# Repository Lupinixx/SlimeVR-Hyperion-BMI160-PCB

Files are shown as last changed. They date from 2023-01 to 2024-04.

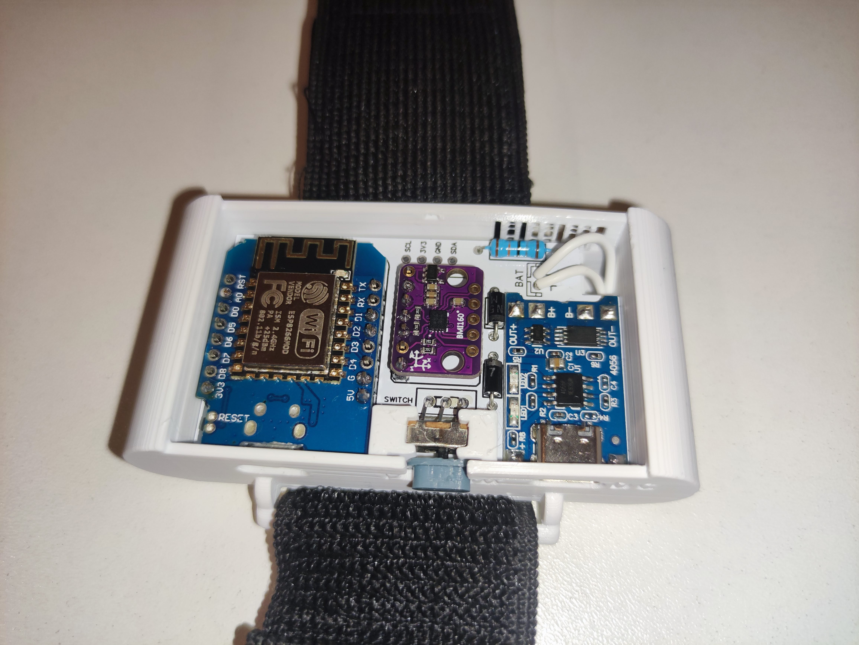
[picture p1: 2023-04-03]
Photos/IMG_20230331_202753.jpg

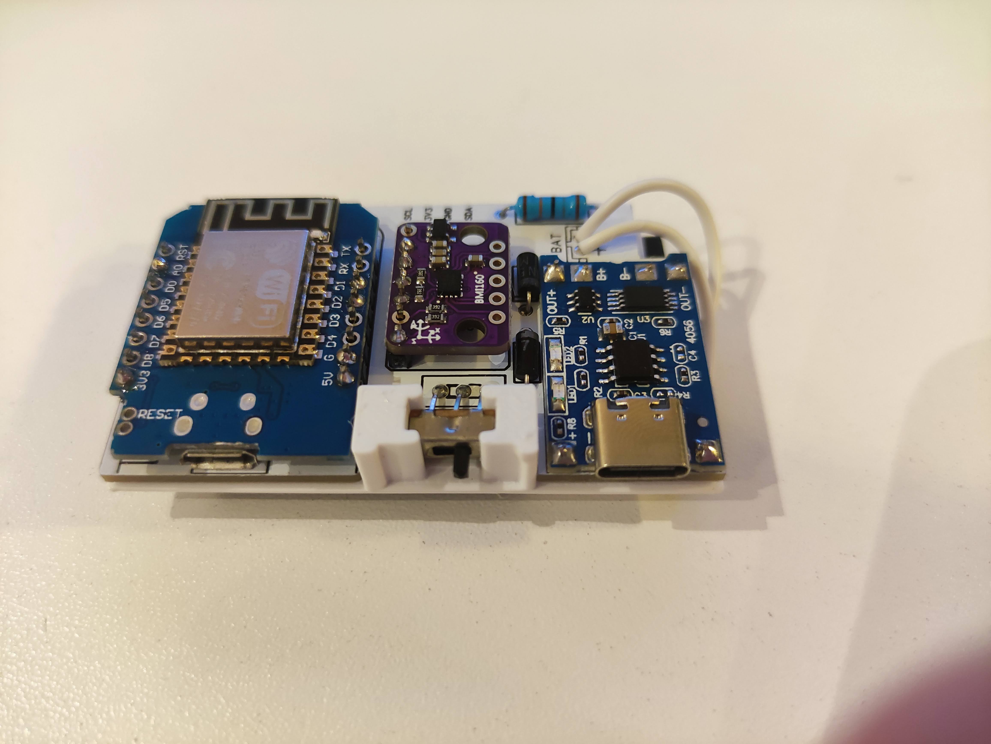
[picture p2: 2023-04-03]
Photos/IMG_20230331_202522.jpg

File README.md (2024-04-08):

# Direct order from PCBWay (This does support me a bit!)
https://www.pcbway.com/project/shareproject/SlimeVR_Hyperion_BMI160_PCB_ddd64fe3.html

# Modified Hyperion case for SlimeVR with PCB for BMI160 IMU

This is a modified version Hyperion case made to fit a custom made PCB that holds standard SlimeVR components and a BMI160 IMU. <br>
Includes a modified lid with holes to allow you to see the LEDs on the PCB inside. <br>
The original design of the case is made by Smeltie and can be found here: https://github.com/Smeltie/Hyperion <br>
The 804040 battery variant of the case is made by Discord user 'Tamate Momochi#9595' <br>
The STEP Conversion was provided by [The4thGoose](https://github.com/The4thGoose) <br>

## Components
This Case/PCB is made for the standard DIY SlimeVR components that are recommended in the docs. you can check the docs for links to the specific componets here: https://docs.slimevr.dev/diy/components-guide.html <br>
Only difference is to the docs the switch used, which is smaller and looks nicer (standard for the hyperion case) <br>
The IMU used is the BMI160. <br>

- TP4056
- Wemos D1 Mini
- BMI160
- 40MM Straps
- SS12D00G3 (switch)
- Battery
    - 503759 (Nokia BL-5C also fits this version and is also a cheap alternative. Bit harder to solder as it does not come with battery leads.)
    - 804040
- 1N5817 Diode (2x)
- 180K Ohm resistor

## PCB
Included in this repo are the gerber files that can be uploaded at [JLCPCB](https://jlcpcb.com/) <br>
Or you can directly order from PCBWay from here https://www.pcbway.com/project/shareproject/SlimeVR_Hyperion_BMI160_PCB_ddd64fe3.html
The source of this PCB can be found at:  https://oshwlab.com/lupinix/slimevr-hyperion-bmi160

## Building
The PCB is made for the above mentions components to be soldered on with the pin headers that are (almost always) included with those components.
The TP4056 however has to be directly soldered to the PCB so there is no gap between PCB and the TP4056. What I like to do is lign up the holes of the TP4056 and the PCB and then throw in a short snipped off resistor lead, and then solder it from both sides. This way you can be sure there is electrical contact between the PCB and TP4056. <br>
The Resistor and diodes can just be soldered like a regular troughhole component. <br>
For the switch I reccomend to first solder everything else, put the PCB on the 3D printed tray, then push the switch in place and solder it.

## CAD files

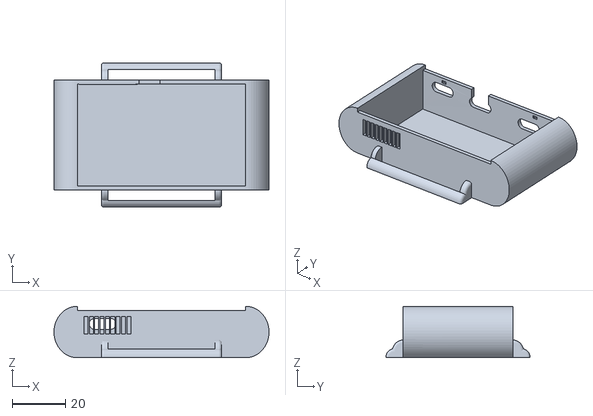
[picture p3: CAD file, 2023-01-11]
503759 case/Case_503759.stl
80.5 x 54.0 x 19.2

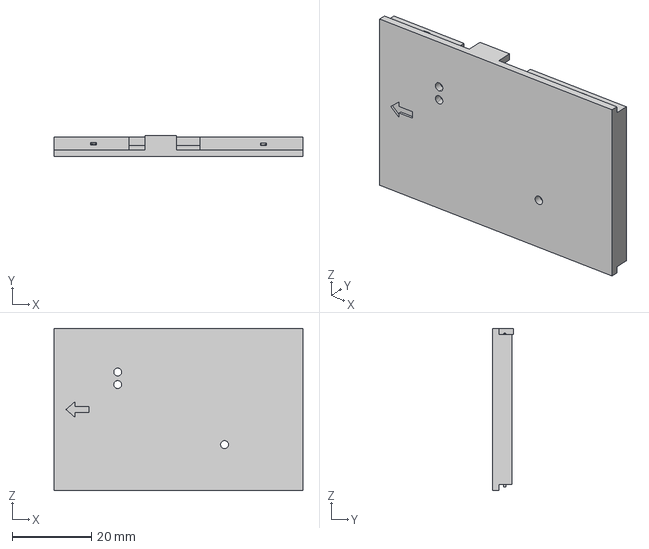
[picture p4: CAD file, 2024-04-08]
503759 case/STEP Files/Lid.step
63.0 x 5.37 x 41.0 mm

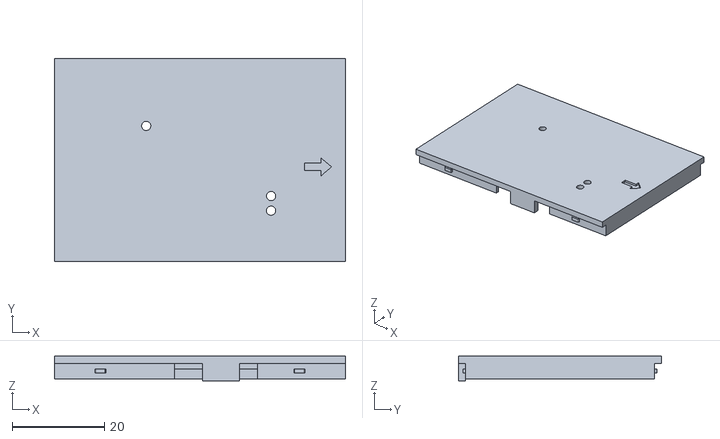
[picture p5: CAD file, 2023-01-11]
804040 case/Lid_804040.stl
63.0 x 44.0 x 5.37

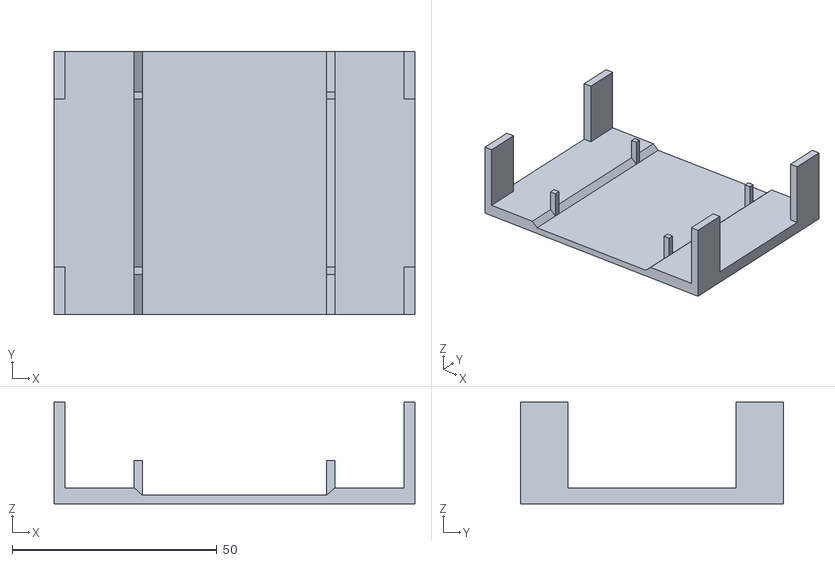
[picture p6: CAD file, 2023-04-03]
Hyperion Lupinix-calibration_jig.stl
88.1 x 64.1 x 24.8

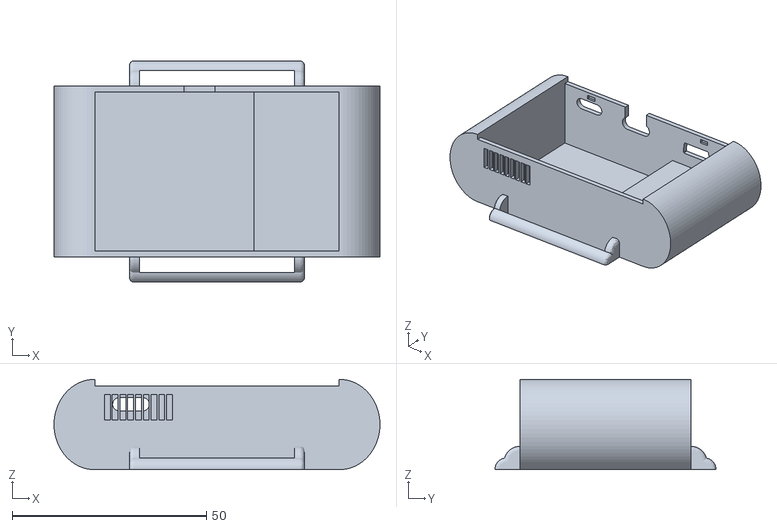
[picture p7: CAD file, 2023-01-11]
804040 case/Case_804040.stl
84.0 x 57.0 x 23.3

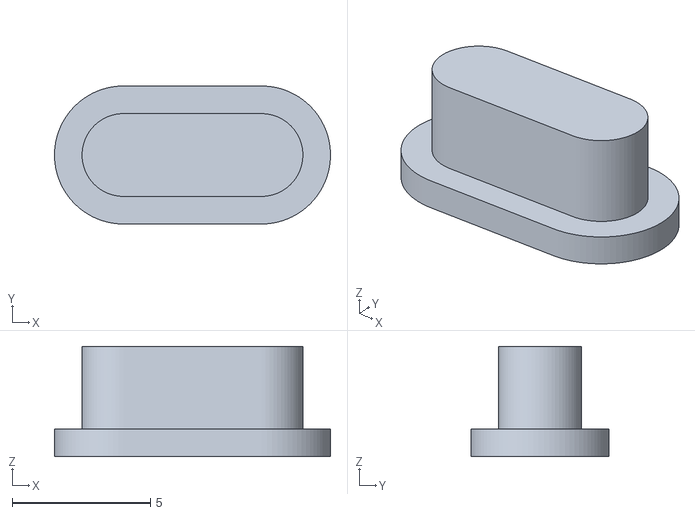
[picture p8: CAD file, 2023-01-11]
Switch.stl
10.00 x 5.00 x 4.00

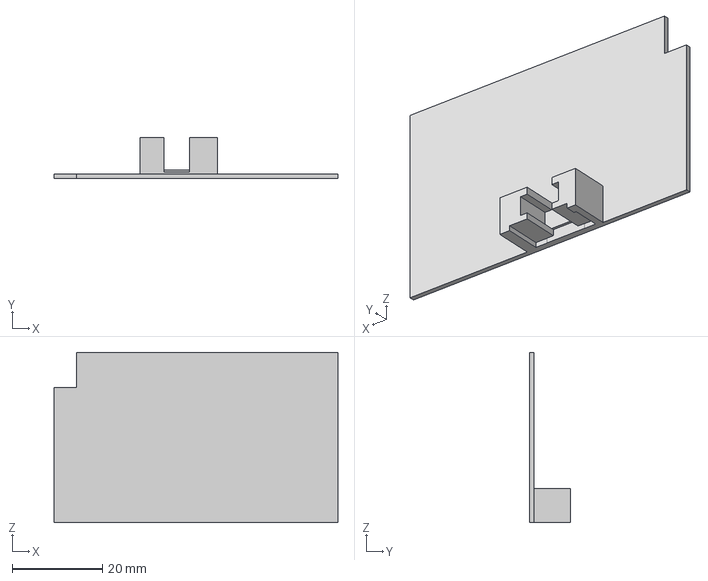
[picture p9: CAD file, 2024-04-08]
503759 case/STEP Files/Tray.step
62.9 x 9.00 x 37.7 mm

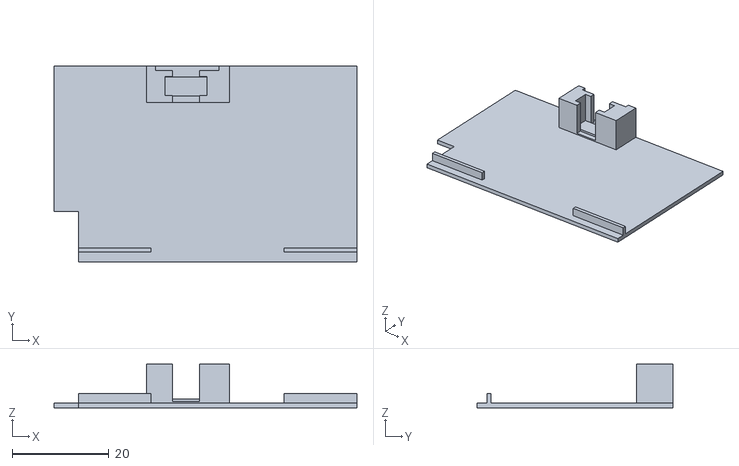
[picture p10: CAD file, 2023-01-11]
804040 case/Tray_804040.stl
62.5 x 40.5 x 9.00

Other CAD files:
503759 case/Lid_503759_Blank.stl
503759 case/STEP Files/Case.step
503759 case/Tray_503759.stl

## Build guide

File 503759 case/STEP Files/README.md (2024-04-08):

## Disclaimer
*These files are a conversion of the .stl files in fusion 360. They may not be 100% accurate, but they should be close enough to be useful for modifications to the case.*

These files should be program agnostic, but I have only tested them in Fusion 360.

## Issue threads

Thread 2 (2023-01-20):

Purpose of holes in lid?

RAnders00, 2023-01-20:
I wasn't able to figure out the purpose of the three holes in the lid. What are they for?

ADAM1631, 2023-01-21:
The holes are for the D1 mini and TP4056 LED lights to be easily viewed.

Closed 2023-01-25.

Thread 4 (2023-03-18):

Documentation: add images of the completed PCB installed in the case

SniderThanYou, 2023-03-18:
Hey! Thanks so much for sharing this project. It looks like the recommended SS12D00G3 switches sit flush to the board, but the case looks like the switch should be mounted sideways. Would you add a picture or two showing how you made it work? Thanks!

DoctorBlobs, 2023-03-28:
I would also really like to see how that was done, cheers!

Lupinixx, 2023-04-03:
Added some images in the Image folder

Closed 2023-04-03.

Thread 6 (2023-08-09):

Possible Modifications for AUX trackers

Lavasteam-Ariz, 2023-08-09:
I've noticed that the cases don't have an AUX port. The PCB already has holes for extensions

eNesPL, 2023-12-01:
+1

ItsSkynet, 2024-04-20:
would love to see that too, not just something like the regular hyperions have (a small hole for cables to pass trough), but a large hole that can support a JST 4pin angled needle connector.
reference: [AliExpress Item](https://es.aliexpress.com/item/1005002431412295.html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)

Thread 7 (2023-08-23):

D1 Mini has its USB-C port mounted on the top, leading to too large of an offset

InconsolableCellist, 2023-08-23:
I'm using the D1 mini for assembly, and putting it on the normal pin headers and placing it on top of the PCB, the USB-C port doesn't line up with the cut-out in the case. This also means the lid won't close properly. I noticed in the photos that the ESP32 you're using has a micro USB port mounted on the bottom of its modular board, which lines up.

Would it be possible to make a D1 variant? It'd also be nice if the TP4056 could be mounted on normal pin headers too, with that ~1mm vertical offset, as it makes it easier and faster to solder.

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

ManicQuinn, 2023-11-19:
They are both D1 Mini's, the difference is that your's is V4.0, they're quite different, case wasn't designed for it

InconsolableCellist, 2023-11-19:
I should've come back and updated this. The issue I was having was because I kept the spacers on the pin headers, elevating it and making it not quite fit. I deviated from the instructions which said the D1 Mini should lay flat on the PCB. I think the version I have will still fit fine, though I went on and made a new PCB just to fit in the BNO085.

Closed 2023-11-19.

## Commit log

2023-01-11 Added STLs for 503759 battery case
    [Hyperion Lupinix-Case_503759.stl, Hyperion Lupinix-Lid_503759_Blank.stl, Hyperion Lupinix-Tray_503759.stl]
2023-01-11 Added gerber zip with the PCB
2023-01-11 Added 804040 cases
    [Case_503759.stl, Case_804040.stl, Lid_503759_Blank.stl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]
2023-01-11 renamed cases
    [Hyperion Lupinix-Case_503759.stl, Hyperion Lupinix-Lid_503759_Blank.stl, Hyperion Lupinix-Tray_503759.stl]
2023-01-22 Document purpose of holes in lid
    Closes #2
2023-04-03 Added calibration jig
    [Hyperion Lupinix-calibration_jig.stl]
2024-04-05 Added step conversions
    In the process of making my own modifications for mounting to a gopro harness, I converted the stl's to steps. These won't be 100% accurate, but should be good enough for FDM printers.
    [Case.step, Lid.step, Tray.step]
